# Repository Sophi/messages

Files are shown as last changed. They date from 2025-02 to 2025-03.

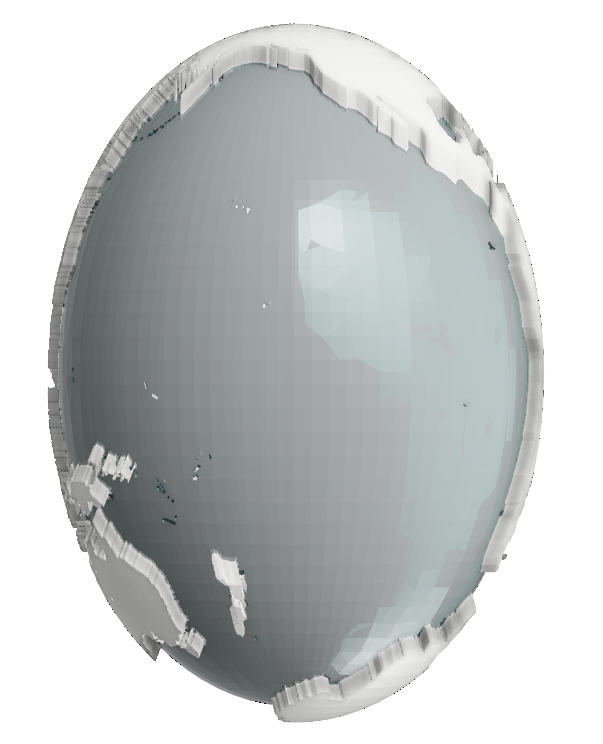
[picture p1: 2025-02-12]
extras/globe v2 screenshots/Screenshot 2024-12-30 113259.png

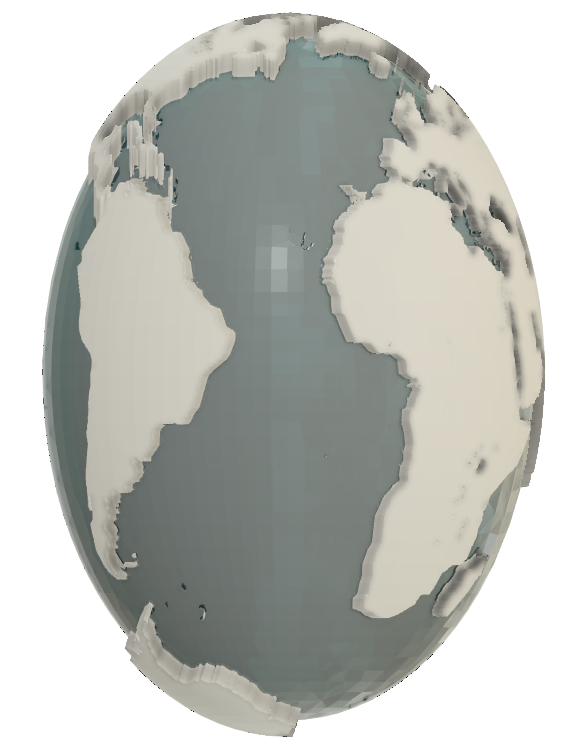
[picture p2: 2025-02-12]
extras/globe v2 screenshots/Screenshot 2024-12-30 112406.png

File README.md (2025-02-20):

# messages
WIP!

Imagine a field of glowing, planet-like orbs floating above you, each one pulsing with an unseen cosmic rhythm. These cosmic eggs capture real cosmic rays —high-energy particles from space— and translates them into an evolving, generated soundscape. The result is an unpredictable, meditative audio experience, where Space itself becomes an invisible composer. Lying beneath them, you hear the universe whisper in tones that are ethereal, textured, and deeply immersive. It’s a piece about connection, inviting us to rethink Earth’s place in the cosmos.

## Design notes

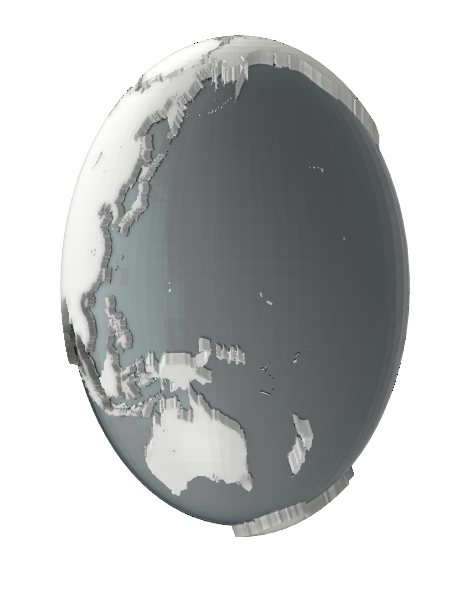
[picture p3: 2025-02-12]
extras/globe v2 screenshots/Screenshot 2024-12-30 111828.png

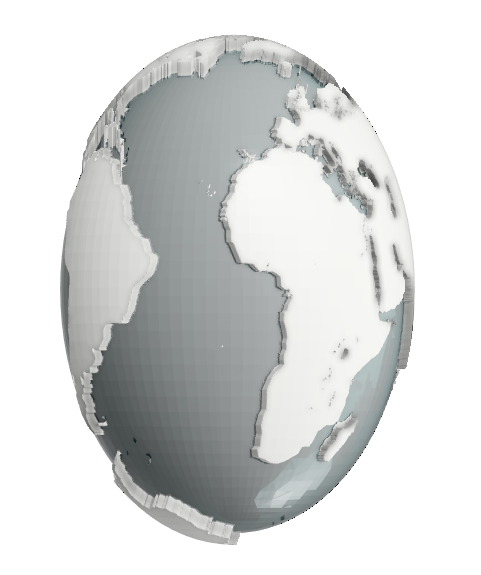
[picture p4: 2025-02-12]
extras/globe v2 screenshots/Screenshot 2024-12-30 104859.png

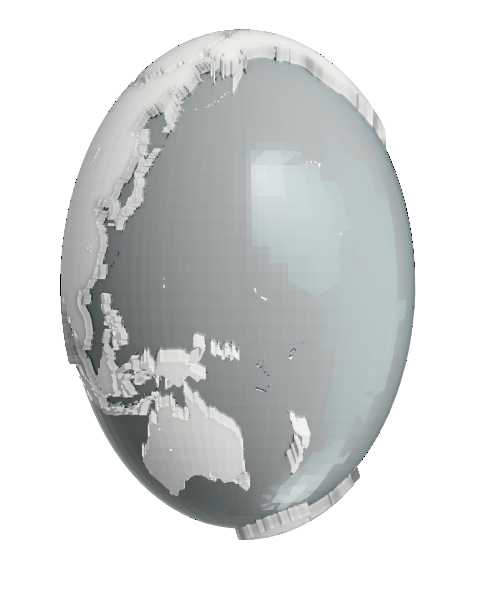
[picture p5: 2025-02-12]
extras/globe v2 screenshots/Screenshot 2024-12-30 104828.png

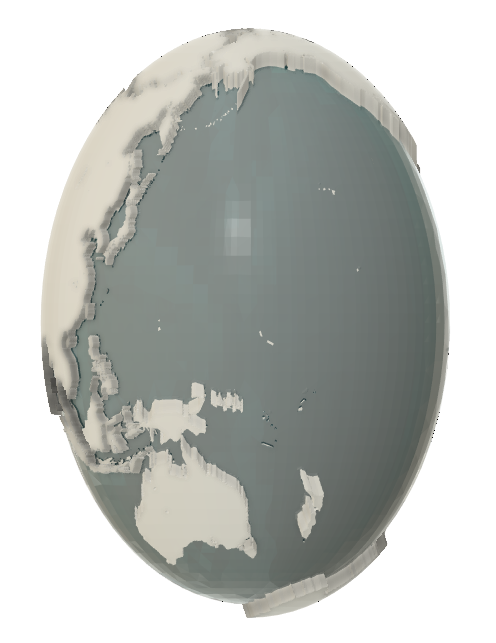
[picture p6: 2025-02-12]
extras/globe v2 screenshots/Screenshot 2024-12-30 111813.png

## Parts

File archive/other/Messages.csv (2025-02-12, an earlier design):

Reference | Value | Footprint | Qty | MPN | ALT MPN
C1 | 1uF/ 500V | Capacitor_SMD:C_2220_5750Metric | 1 | CHV2220N500105KXT
C2,C3,C17,C19,C20,C21,C22,C23,C24 | 0.1uF | Capacitor_SMD:C_0805_2012Metric | 9 | CC0805KRX7R9BB104
C4 | 120pF | Capacitor_SMD:C_0805_2012Metric | 1 | C0805C121J5GACTU
C5,C6,C10 | 1uF | Capacitor_SMD:C_0805_2012Metric | 3 | CC0805KKX5R6BB105
C7,C8,C9,C16,C18 | 10uF | Capacitor_SMD:C_0805_2012Metric | 5 | CL21B106KPQNNNE
C11,C12,C25 | 0.01uF | Capacitor_SMD:C_0805_2012Metric | 3 | C0805C103K5RACTU
C13,C26 | 2.2uF | Capacitor_SMD:C_0805_2012Metric | 2 | LMK212BJ225KD-T
C14,C15 | 2.2nF | Capacitor_SMD:C_0805_2012Metric | 2 | LMK212BJ225KD-T
D1 | ES1H | ES1H:DIOM4226X244N | 1 | ES1H
D2,D14 | YELLOW | LED_SMD:LED_0805_2012Metric | 2 | 150080YS75000
D3 | D_Schottky | Diode_SMD:D_SOD-323 | 1 | 1SS367,H3F
D4,D8 | GREEN | LED_SMD:LED_0805_2012Metric | 2 | 150080GS75000
D5,D6,D7,D10,D11,D12 | ESD9B5.0ST5G | Diode_SMD:D_SOD-923 | 6 | ESD9B5.0ST5G
D9,D13 | BLUE | LED_SMD:LED_0805_2012Metric | 2 | -- mixed values --
F1 | Clip | Fuse:Fuseholder_Clip-7.62mm_Littelfuse | 1 | 01220088Z
J1,J2 | USB4105-GF-A | USB4105-GF-A:GCT_USB4105-GF-A | 2 | USB4105-GF-A
J3 | AUDIO JACK | STX_3000:STX-3000_KYC | 1 | STX-3000
J4 | MEM2061-01-188-00-A | MEM2061 SD CARD CONNECTOR:MEM2061-01-188-00-A_GCT | 1 | MEM2061-01-188-00-A
J5 | 1x6 header | Connector_PinHeader_2.54mm:PinHeader_1x06_P2.54mm_Vertical | 1 | 61300611121
L1 | 2.2uH | Inductor_SMD:L_1008_2520Metric | 1 | DFE252012F-2R2M=P2
LS1 | CMI-1295IC-0385T | CMI_1295IC_0385T:CUI_CMI-1295IC-0385T | 1 | CMI-1295IC-0385T
Q1 | AO3400A | Package_TO_SOT_SMD:SOT-23 | 1 | AO3400A
Q2,Q3 | 2N7002-TP | Package_TO_SOT_THT:TO-92_Inline | 2 | 2N7002-TP
Q4 | BC846 | Package_TO_SOT_SMD:SOT-23 | 1 | BC846B_R1_00001
R1,R2 | 220R | Resistor_SMD:R_0805_2012Metric | 2 | RK73B2ATTD221J
R3 | 560k, 1M | Resistor_SMD:R_2512_6332Metric | 1 | CRGP2512F560K | CRGP2512F1M0
R4 | 715R | Resistor_SMD:R_0805_2012Metric | 1 | CRCW0805715RFKEA
R5 | 1K | Resistor_SMD:R_0805_2012Metric | 1 | RNCP0805FTD1K00
R6,R8,R23,R24,R28 | 4.7k | Resistor_SMD:R_0805_2012Metric | 5 | CRCW08054K70FKEAC
R7 | 5R | Resistor_SMD:R_0805_2012Metric | 1 | RC0805FR-0710RL | RMCF0603FT10R0
R9 | 2.7k | Resistor_SMD:R_0805_2012Metric | 1 | CRG0805F2K7
R10,R11,R13,R16,R20,R22,R32,R33,R34 | 10k | Resistor_SMD:R_0805_2012Metric | 9 | RMCF0805FT10K0
R12,R14,R18,R21 | 5.1k | Resistor_SMD:R_0805_2012Metric | 4 | RC0805JR-075K1L
R15,R31 | 1M | Resistor_SMD:R_0805_2012Metric | 2 | RC0805JR-071ML
R17,R19 | 22R | Resistor_SMD:R_0805_2012Metric | 2 | RC0805FR-0722RL
R25,R26,R27 | 33R | Resistor_SMD:R_0805_2012Metric | 3 | RC0805FR-0733RL
R29,R30 | 470R | Resistor_SMD:R_0805_2012Metric | 2 | CRGCQ0805J470R
S1,S2,S3 | SKRPABE010 | SKRPABE010:SW_SKRPABE010 | 3 | SKRPABE010
S4 | DS04-254-2-06BK-SMT | DIP switch:DIP SWITCH SW_DS04-254-2-06BK-SMT | 1 | DS04-254-2-06BK-SMT
T1 | FL2810-1L | Transformer_SMD:Transformer_Coilcraft_FL2810-1L | 1 | FL2810-1L
U1 | TPS2115APWR | TPS2115APWR:PW8 | 1 | TPS2115APWR
U2 | RP115X | Package_TO_SOT_SMD:SOT-89-5 | 1 | RP115H331D-T1-FE
U3 | TPS613222ADBV | Package_TO_SOT_SMD:SOT-23-5 | 1 | TPS613222ADBV
U4 | ESP32-S3-WROOM-1-N8 | KiCad:ESP32S3WROOM1N8R2 | 1 | ESP32-S3-WROOM-1-N8
U5 | FT231XS | Package_SO:SSOP-20_3.9x8.7mm_P0.635mm | 1 | FT231XS-R
U6 | PCM5102 | Package_SO:TSSOP-20_4.4x6.5mm_P0.65mm | 1 | PCM5102APWR

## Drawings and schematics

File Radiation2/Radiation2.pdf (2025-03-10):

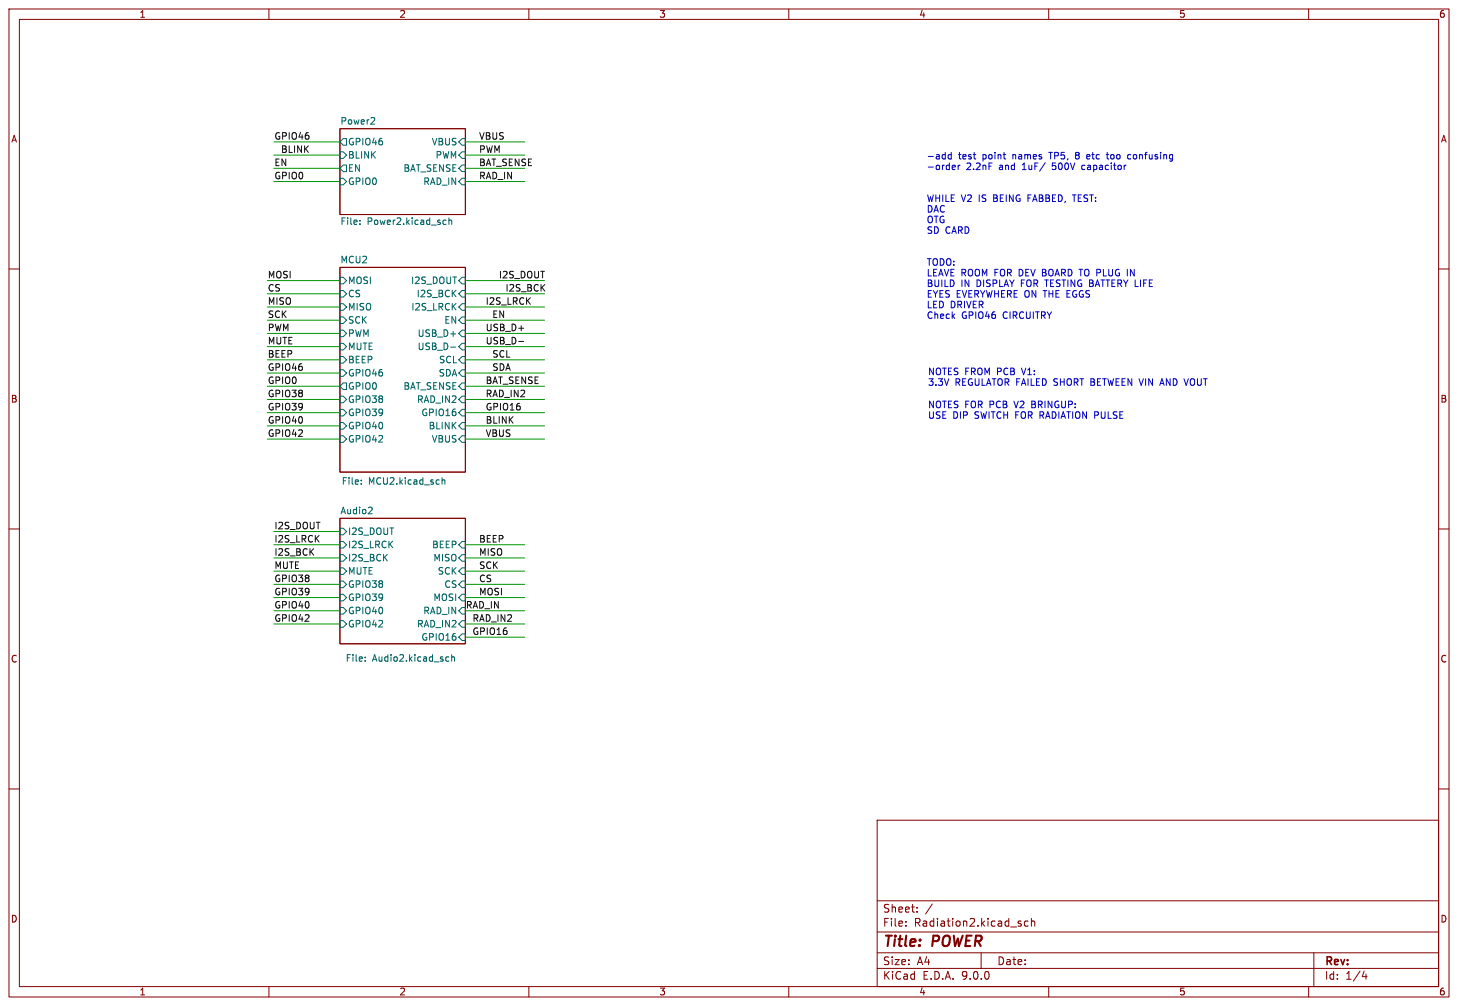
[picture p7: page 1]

TODO: LEAVE ROOM FOR DEV BOARD TO PLUG IN

BUILD IN DISPLAY FOR TESTING BATTERY LIFE
EYES EVERYWHERE ON THE EGGS
LED DRIVER
Check GPIO46 CIRCUITRY

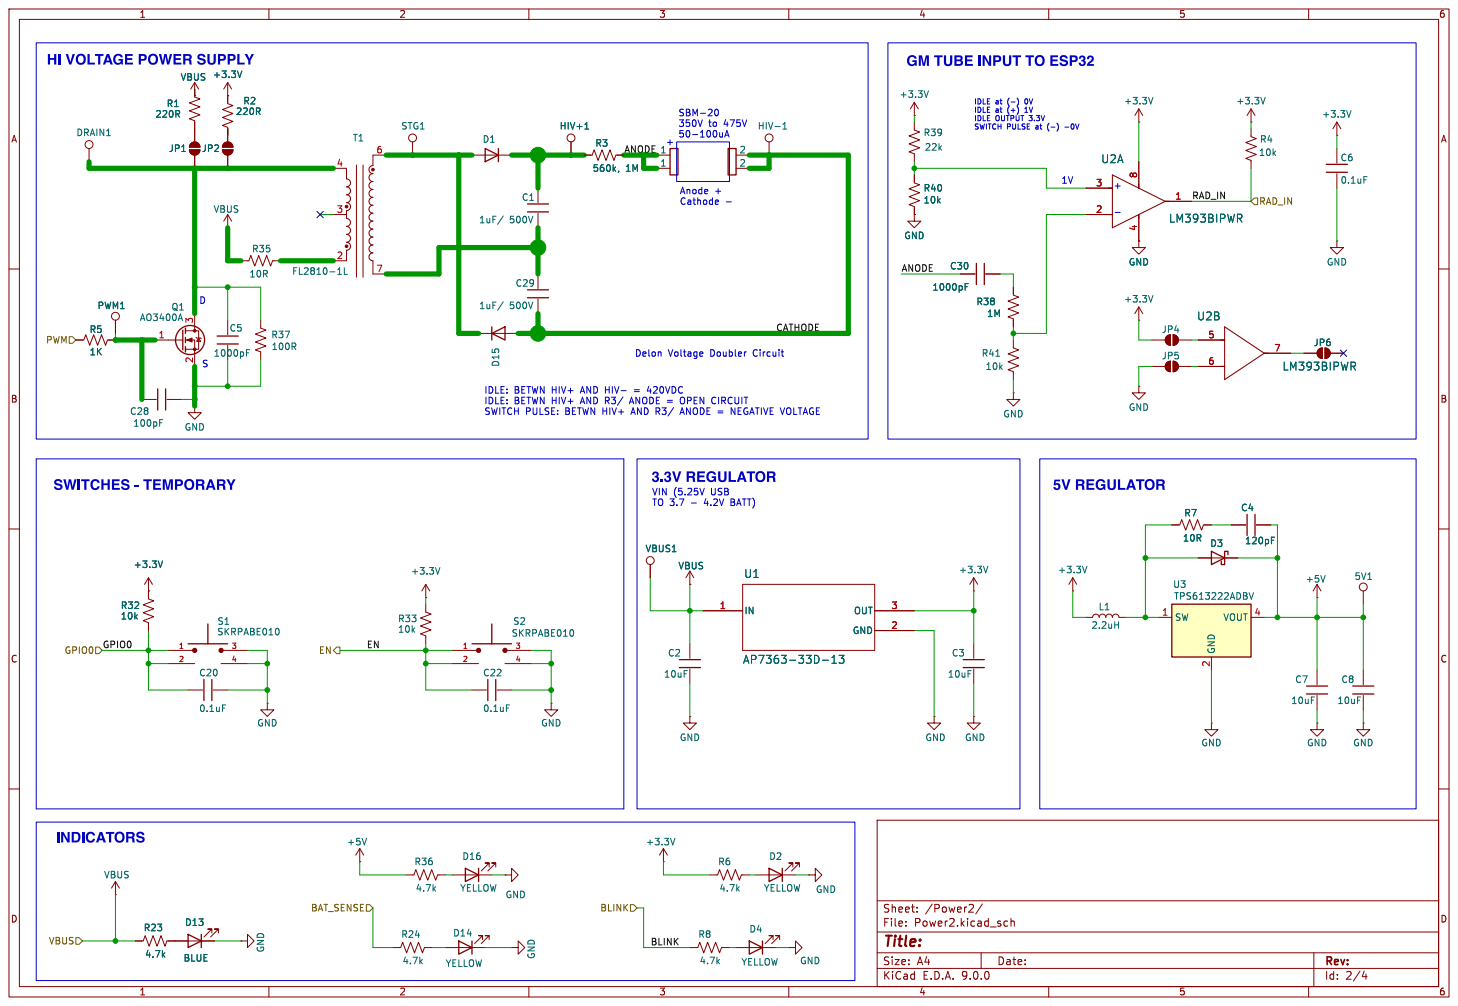
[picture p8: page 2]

Anode + Cathode - VIN (5.25V USB

PWM
TO 3.7 - 4.2V BATT) S SWITCHES - TEMPORARY

IDLE: BETWN HIV+ AND HIV- = 420VDC
IDLE: BETWN HIV+ AND R3/ ANODE = OPEN CIRCUIT SWITCH PULSE: BETWN HIV+ AND R3/ ANODE = NEGATIVE VOLTAGE

Id: 2/4 Title: File: Power2.kicad_sch Sheet: /Power2/

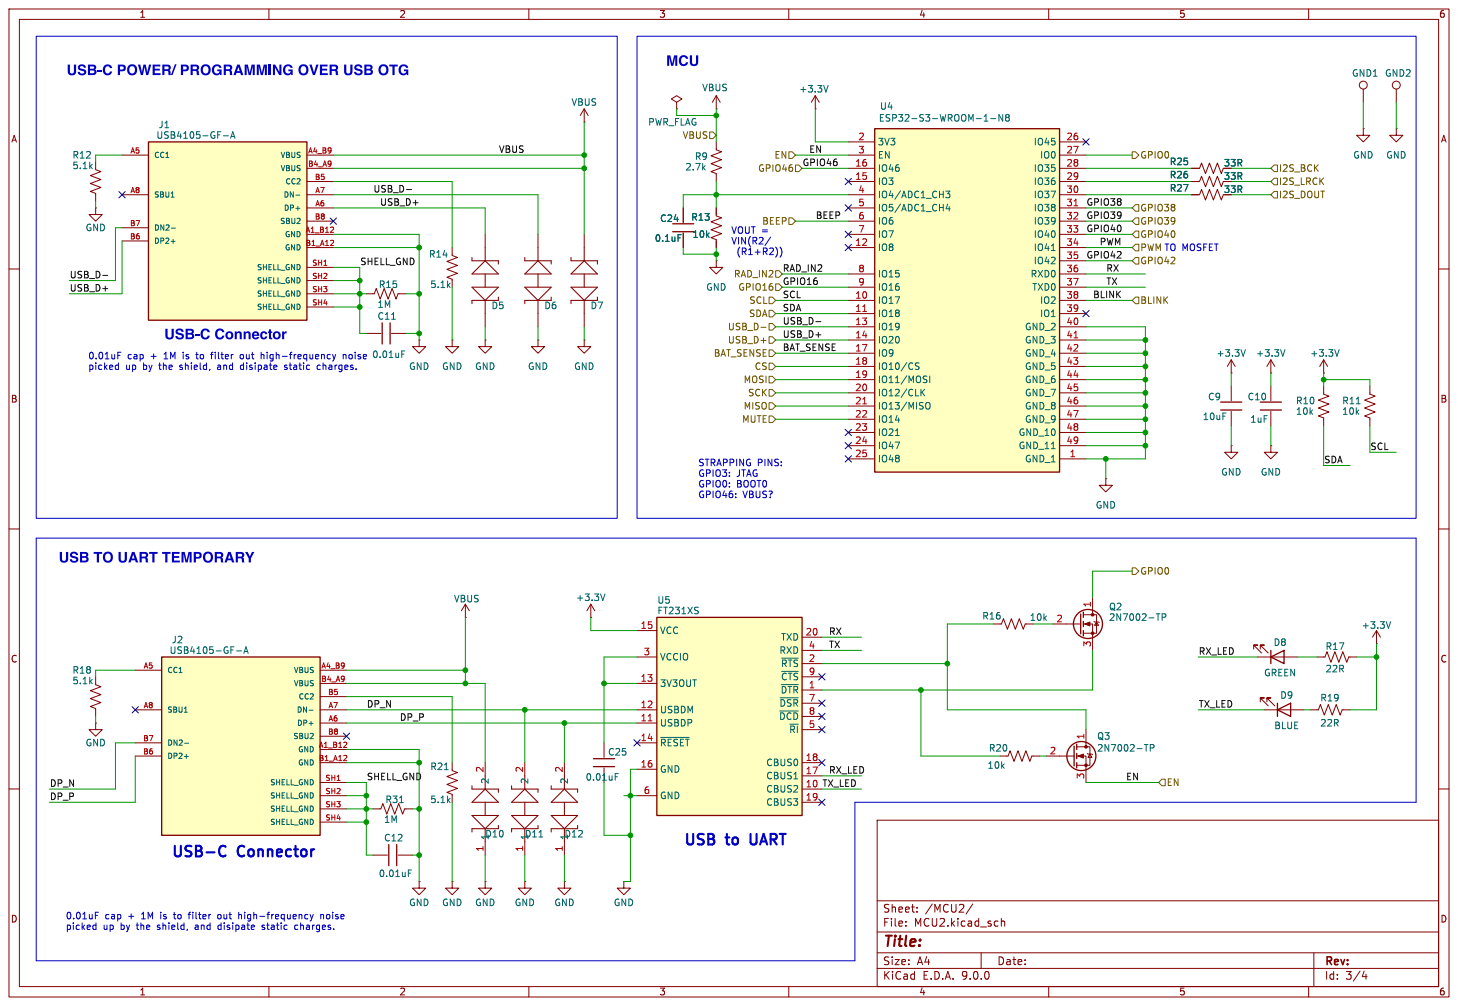
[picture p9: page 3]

USB-C POWER/ PROGRAMMING OVER USB OTG

22R GND
TO MOSFET USB TO UART TEMPORARY

Id: 3/4 Title: File: MCU2.kicad_sch Sheet: /MCU2/

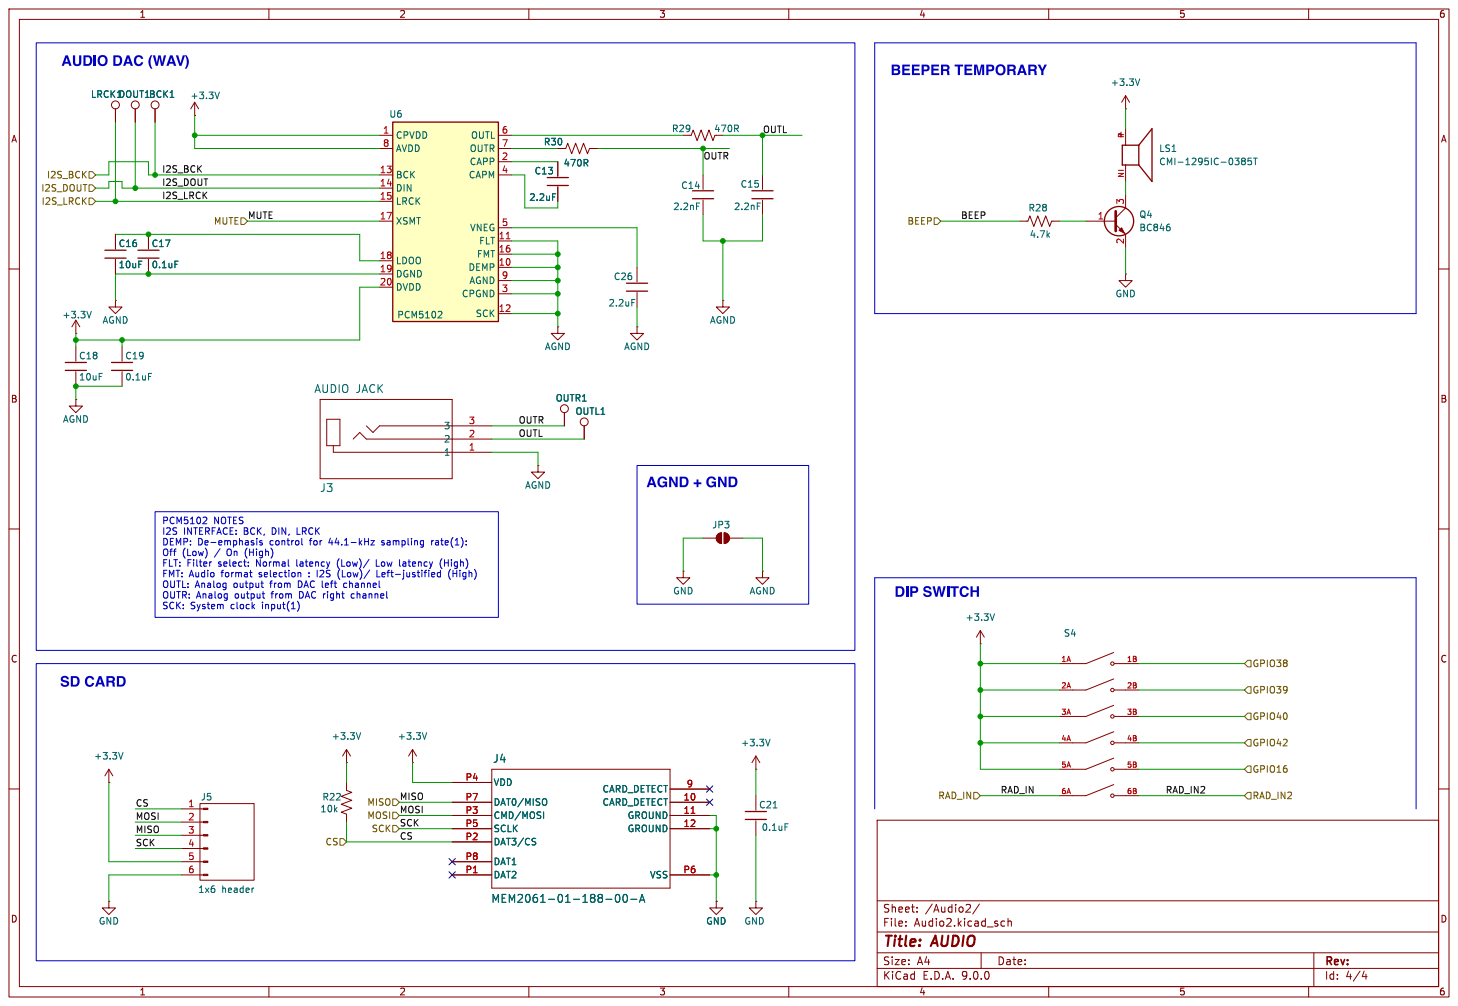
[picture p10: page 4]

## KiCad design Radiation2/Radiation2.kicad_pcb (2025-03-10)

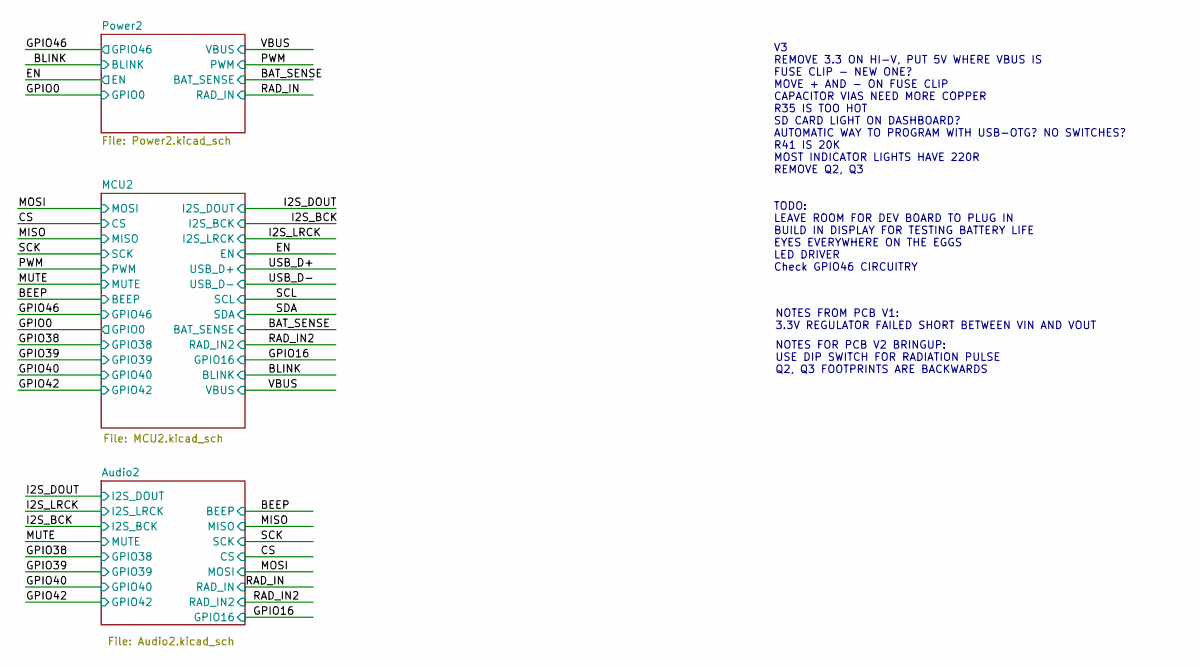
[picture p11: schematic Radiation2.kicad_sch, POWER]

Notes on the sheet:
V3 REMOVE 3.3 ON HI-V, PUT 5V WHERE VBUS IS FUSE CLIP - NEW ONE? MOVE + AND - ON FUSE CLIP CAPACITOR VIAS NEED MORE COPPER R35 IS TOO HOT SD CARD LIGHT ON DASHBOARD? AUTOMATIC WAY TO PROGRAM WITH USB-OTG? NO SWITCHES? R41 IS 20K MOST INDICATOR LIGHTS HAVE 220R REMOVE Q2, Q3 TODO: LEAVE ROOM FOR DEV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
NOTES FOR PCB V2 BRINGUP: USE DIP SWITCH FOR RADIATION PULSE Q2, Q3 FOOTPRINTS ARE BACKWARDS
NOTES FROM PCB V1: 3.3V REGULATOR FAILED SHORT BETWEEN VIN AND VOUT

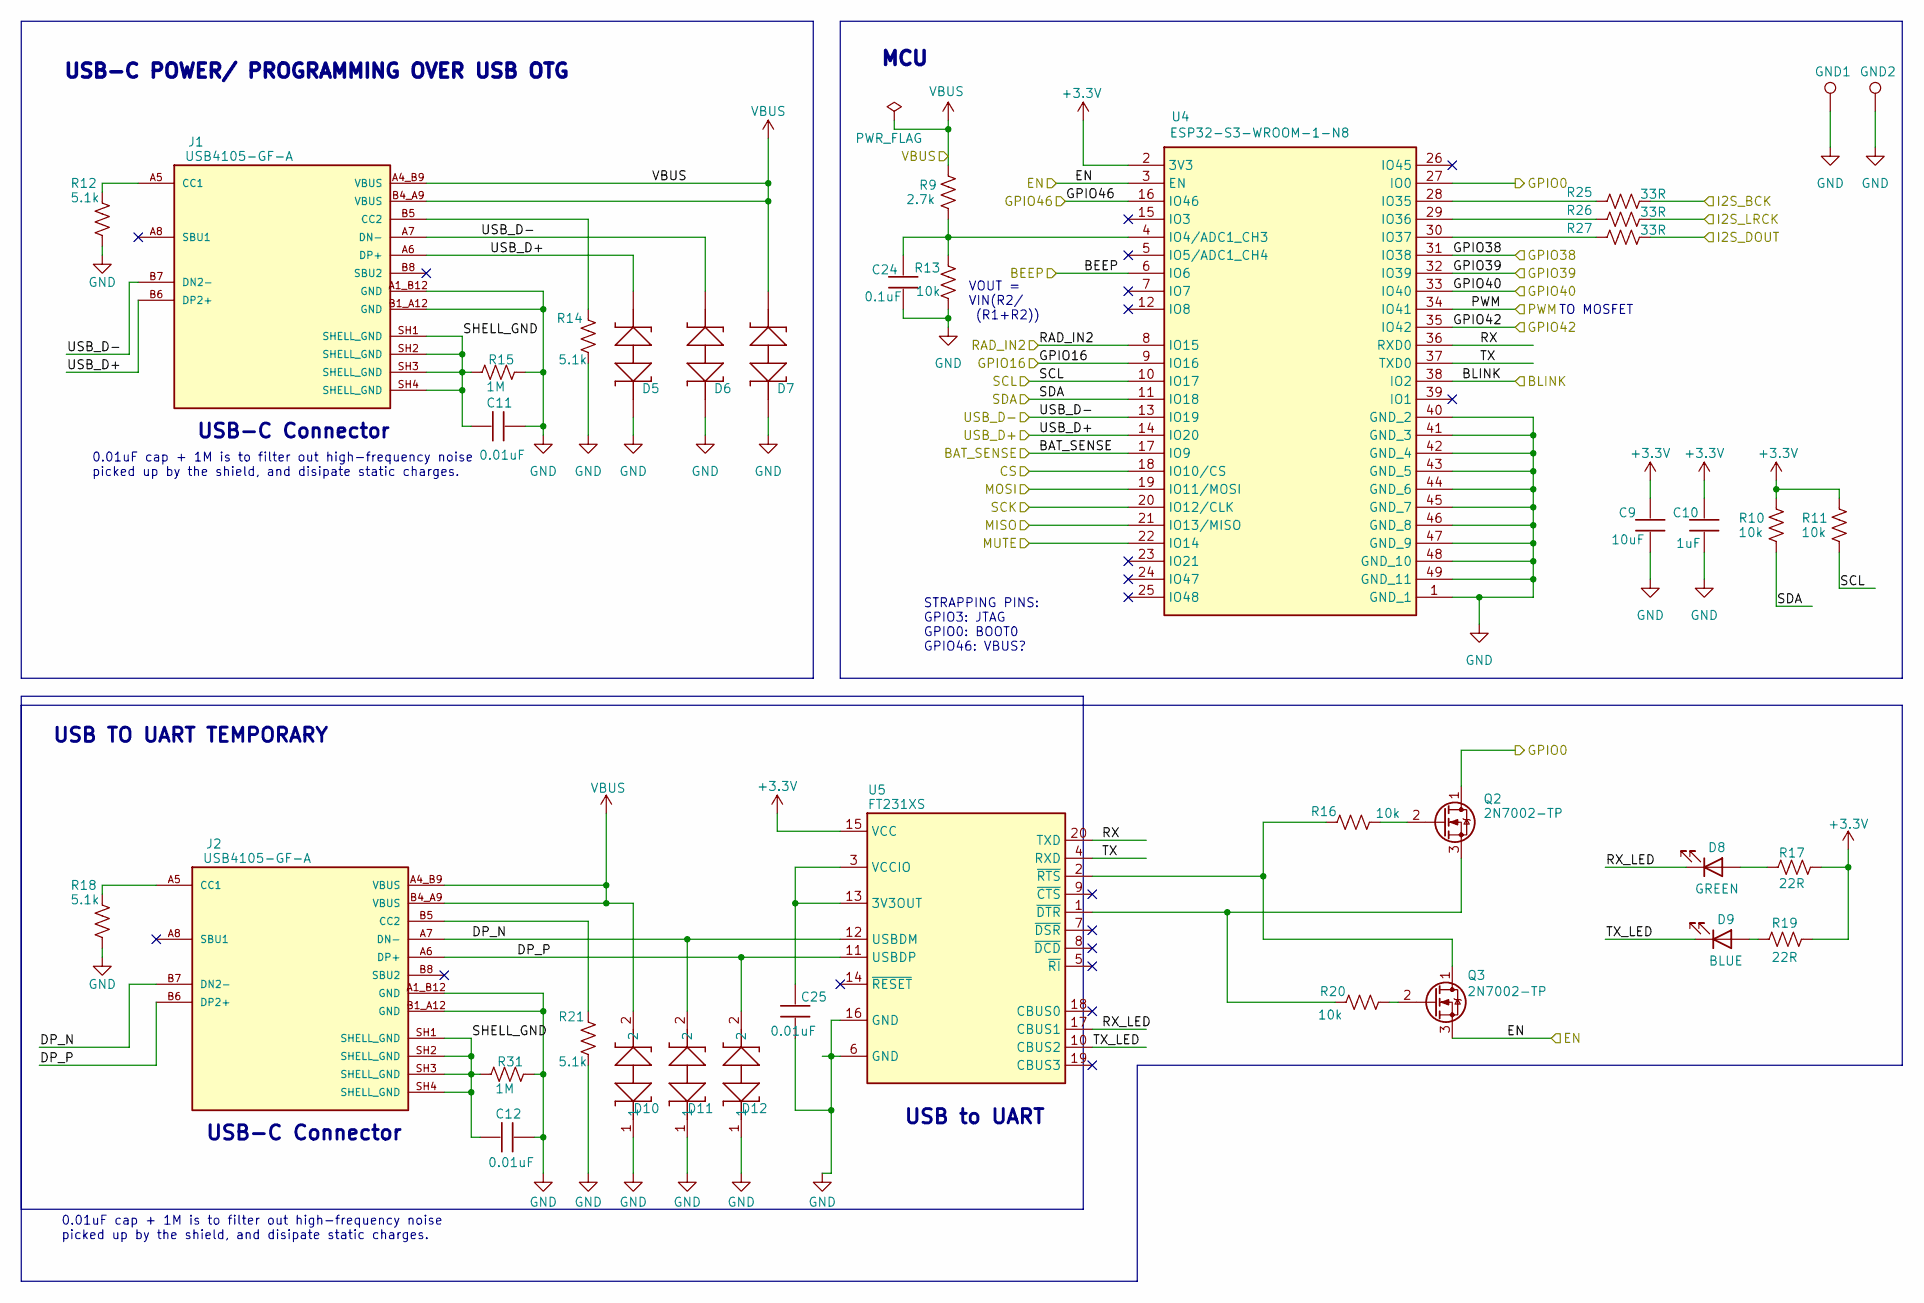
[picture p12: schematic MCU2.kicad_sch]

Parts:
C9: 10uF; C_0805_2012Metric; MPN CL21B106KPQNNNE
C10: 1uF; C_0805_2012Metric; MPN CC0805KKX5R6BB105
C11, C12, C25: 0.01uF; C_0805_2012Metric; MPN C0805C103K5RACTU
C24: 0.1uF; C_0805_2012Metric; MPN CC0805KRX7R9BB104
D5, D6, D7, D10, D11, D12: PESD5V0S1BA; SOD323_NXP; MPN PESD5V0S1BA,115
D8: GREEN; LED_0805_2012Metric; MPN 150080GS75000
D9: BLUE; LED_0805_2012Metric; MPN 150080BS75000
GND1, GND2: TestPoint; Pin_D1.0mm_L10.0mm
J1, J2: USB4105-GF-A; GCT_USB4105-GF-A; MPN USB4105-GF-A
Q2, Q3: 2N7002-TP; SOT-23; MPN 2N7002-TP
R9: 2.7k; R_0805_2012Metric; MPN CRG0805F2K7
R10, R11, R13, R16, R20: 10k; R_0805_2012Metric; MPN RMCF0805FT10K0
R12, R14, R18, R21: 5.1k; R_0805_2012Metric; MPN RC0805JR-075K1L
R15, R31: 1M; R_0805_2012Metric; MPN RC0805JR-071ML
R17, R19: 22R; R_0805_2012Metric; MPN RC0805FR-0722RL
R25, R26, R27: 33R; R_0805_2012Metric; MPN RC0805FR-0733RL
U4: ESP32-S3-WROOM-1-N8; ESP32S3WROOM1N8R2; Mouser Part Number 356-ESP32-S3WROOM1N8
U5: FT231XS; SSOP-20_3.9x8.7mm_P0.635mm; MPN FT231XS-R

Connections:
+3.3V: C9.1, C10.1, R10.2, R11.2, R17.1, R19.1, U4.2 (3V3), U5.15 (VCC); also elsewhere on the board
/BAT_SENSE: U4.17 (IO9); also elsewhere on the board
/BEEP: U4.6 (IO6); also elsewhere on the board
/BLINK: U4.38 (IO2); also elsewhere on the board
/CS: U4.18 (IO10/CS); also elsewhere on the board
/EN: Q3.3 (S), U4.3 (EN); also elsewhere on the board
/GPIO0: Q2.1 (D), U4.27 (IO0); also elsewhere on the board
/GPIO16: U4.9 (IO16); also elsewhere on the board
/GPIO38: U4.31 (IO38); also elsewhere on the board
/GPIO39: U4.32 (IO39); also elsewhere on the board
/GPIO40: U4.33 (IO40); also elsewhere on the board
/GPIO42: U4.35 (IO42); also elsewhere on the board
/GPIO46: U4.16 (IO46); also elsewhere on the board
/I2S_BCK: R25.1; also elsewhere on the board
/I2S_DOUT: R27.1; also elsewhere on the board
/I2S_LRCK: R26.1; also elsewhere on the board
/MCU2/DP_N: D11.2, J2.A7 (DN-), J2.B7 (DN2-), U5.12 (USBDM)
/MCU2/DP_P: D12.2, J2.A6 (DP+), J2.B6 (DP2+), U5.11 (USBDP)
/MCU2/RX: U4.36 (RXD0), U5.20 (TXD)
/MCU2/RX_LED: D8.1 (K), U5.17 (CBUS1)
/MCU2/SHELL_GND: C11.2, C12.2, J1.SH1 (SHELL_GND), J1.SH2 (SHELL_GND), J1.SH3 (SHELL_GND), J1.SH4 (SHELL_GND), J2.SH1 (SHELL_GND), J2.SH2 (SHELL_GND), J2.SH3 (SHELL_GND), J2.SH4 (SHELL_GND), R15.1, R31.1
/MCU2/TX: U4.37 (TXD0), U5.4 (RXD)
/MCU2/TX_LED: D9.1 (K), U5.10 (CBUS2)
/MISO: U4.21 (IO13/MISO); also elsewhere on the board
/MOSI: U4.19 (IO11/MOSI); also elsewhere on the board
/MUTE: U4.22 (IO14); also elsewhere on the board
/PWM: U4.34 (IO41); also elsewhere on the board
/RAD_IN2: U4.8 (IO15); also elsewhere on the board
/SCK: U4.20 (IO12/CLK); also elsewhere on the board
/SCL: R11.1, U4.10 (IO17)
/SDA: R10.1, U4.11 (IO18)
/USB_D+: D5.2, J1.A6 (DP+), J1.B6 (DP2+), U4.14 (IO20)
/USB_D-: D6.2, J1.A7 (DN-), J1.B7 (DN2-), U4.13 (IO19)
GND: C9.2, C10.2, C11.1, C12.1, C24.2, C25.1, D5.1, D6.1, D7.1, D10.1, D11.1, D12.1, GND1.1, GND2.1, J1.A1_B12 (GND), J1.B1_A12 (GND), J2.A1_B12 (GND), J2.B1_A12 (GND), R12.2, R13.1, R14.2, R15.2, R18.2, R21.2, R31.2, U4.1 (GND_1), U4.40 (GND_2), U4.41 (GND_3), U4.42 (GND_4), U4.43 (GND_5), U4.44 (GND_6), U4.45 (GND_7), U4.46 (GND_8), U4.47 (GND_9), U4.48 (GND_10), U4.49 (GND_11), U5.6 (GND), U5.16 (GND); also elsewhere on the board
unnamed: D8.2 (A), R17.2
unnamed: D9.2 (A), R19.2
unnamed: J1.A5 (CC1), R12.1
unnamed: J1.B5 (CC2), R14.1
unnamed: J2.A5 (CC1), R18.1
unnamed: J2.B5 (CC2), R21.1
unnamed: Q2.2 (G), R16.1
unnamed: Q2.3 (S), R20.2, U5.1 (~DTR)
unnamed: Q3.1 (D), R16.2, U5.2 (~RTS)
unnamed: Q3.2 (G), R20.1
unnamed: C24.1, R9.1, R13.2, U4.4 (IO4/ADC1_CH3)
unnamed: R25.2, U4.28 (IO35)
unnamed: R26.2, U4.29 (IO36)
unnamed: R27.2, U4.30 (IO37)
unnamed: C25.2, U5.3 (VCCIO), U5.13 (3V3OUT)
VBUS: D7.2, D10.2, J1.A4_B9 (VBUS), J1.B4_A9 (VBUS), J2.A4_B9 (VBUS), J2.B4_A9 (VBUS), R9.2; also elsewhere on the board

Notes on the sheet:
USB-C POWER/ PROGRAMMING OVER USB OTG
0.01uF cap + 1M is to filter out high-frequency noise picked up by the shield, and disipate static charges.
MCU
VOUT = VIN(R2/ (R1+R2))
USB TO UART TEMPORARY
TO MOSFET
USB-C Connector
STRAPPING PINS: GPIO3: JTAG GPIO0: BOOT0 GPIO46: VBUS?
USB to UART

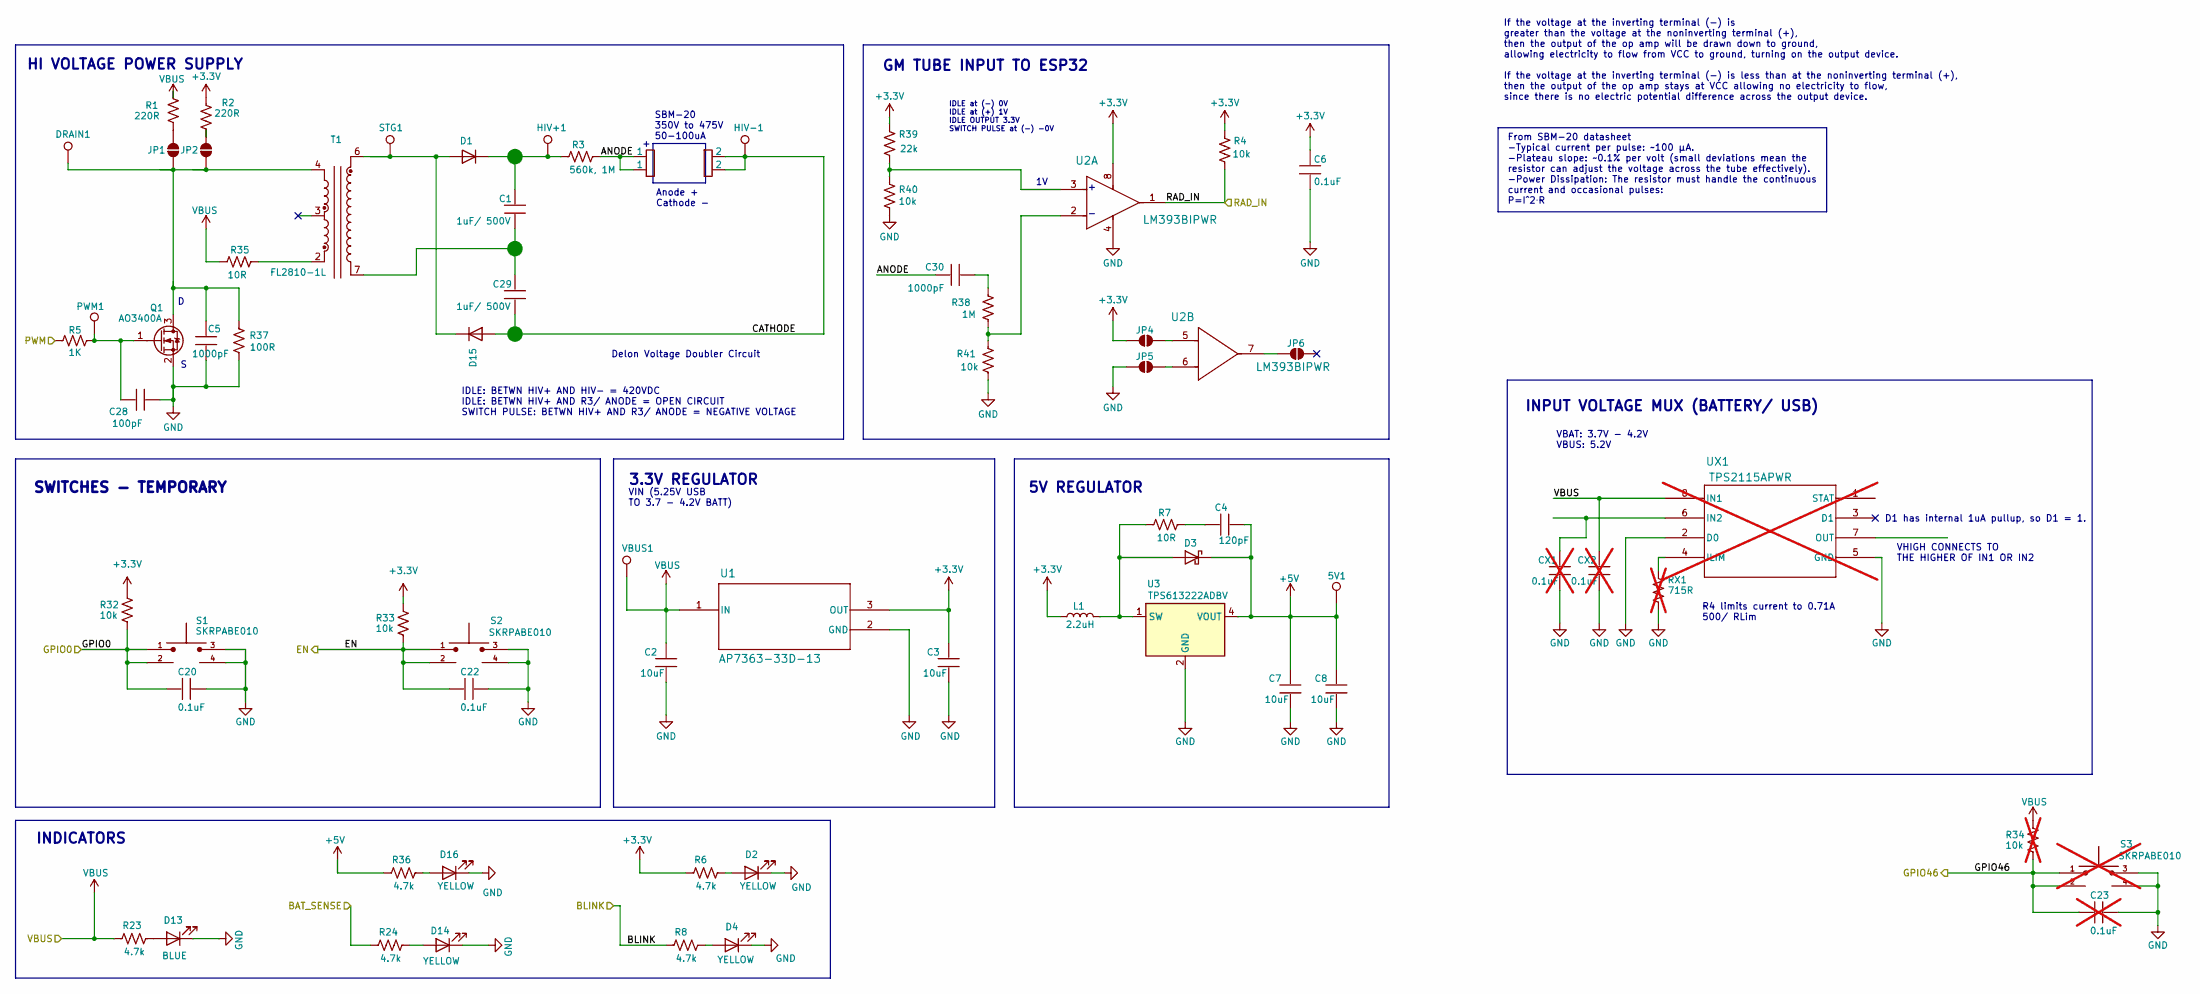
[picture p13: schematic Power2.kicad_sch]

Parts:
5V1: TestPoint; Pin_D1.0mm_L10.0mm
C1, C29: 1uF/ 500V; C_2220_5750Metric; MPN ECW-FD2J105K
C2, C3, C7, C8: 10uF; C_0805_2012Metric; MPN CL21B106KPQNNNE
C4: 120pF; C_0805_2012Metric; MPN C0805C121J5GACTU
C5, C30: 1000pF; C_0805_2012Metric; MPN C2012C0G2W102J060AA
C6, C20, C22: 0.1uF; C_0805_2012Metric; MPN CC0805KRX7R9BB104
C23: 0.1uF; C_0805_2012Metric; MPN CC0805KRX7R9BB104; not fitted
C28: 100pF; C_0805_2012Metric; MPN C0805C101J5GACTU
CX1, CX2: 0.1uF; C_0805_2012Metric; MPN CC0805KRX7R9BB104; not fitted
D1, D15: ES1H; DIOM4226X244N; MPN ES1H
D2, D4, D14, D16: YELLOW; LED_0805_2012Metric; MPN 150080YS75000
D3: D_Schottky; D_SOD-323; MPN 1SS367,H3F
D13: BLUE; LED_0805_2012Metric; MPN 150080BS75000
DRAIN1: TestPoint; Pin_D1.0mm_L10.0mm
F1: Clip; Fuseholder_Clip-7.62mm_Littelfuse; MPN 01220088Z
HIV+1: TestPoint; Pin_D1.0mm_L10.0mm
HIV-1: TestPoint; Pin_D1.0mm_L10.0mm
JP1, JP2, JP4, JP5, JP6: SolderJumper_2_Open; SolderJumper-2_P1.3mm_Open_RoundedPad1.0x1.5mm
L1: 2.2uH; L_1008_2520Metric; MPN DFE252012F-2R2M=P2
PWM1: TestPoint; Pin_D1.0mm_L10.0mm
Q1: AO3400A; SOT-23; MPN AO3400A
R1, R2: 220R; R_0805_2012Metric; MPN RK73B2ATTD221J
R3: 560k, 1M; R_2512_6332Metric; MPN CRGP2512F560K
R4: 10k; R_0805_2012Metric; MPN CRCW08054K70FKEAC
R5: 1K; R_0805_2012Metric; MPN RNCP0805FTD1K00
R6, R8, R23, R24, R36: 4.7k; R_0805_2012Metric; MPN CRCW08054K70FKEAC
R7: 10R; R_0805_2012Metric; MPN RMCF0603FT10R0
R32, R33, R40, R41: 10k; R_0805_2012Metric; MPN RMCF0805FT10K0
R34: 10k; R_0805_2012Metric; MPN RMCF0805FT10K0; not fitted
R35: 10R; R_2512_6332Metric; MPN 352210RJT
R37: 100R; R_0805_2012Metric; MPN ERJ-P06J101V
R38: 1M; R_1210_3225Metric; MPN RC1210FR-071ML
R39: 22k; R_0805_2012Metric; MPN RMCF0805JT22K0
RX1: 715R; R_0805_2012Metric; MPN CRCW0805715RFKEA; not fitted
S1, S2: SKRPABE010; SW_SKRPABE010; MPN SKRPABE010
S3: SKRPABE010; SW_SKRPABE010; MPN SKRPABE010; not fitted
STG1: TestPoint; Pin_D1.0mm_L10.0mm
T1: FL2810-1L; Transformer_Coilcraft_FL2810-1L; MPN FL2810-1L; Mouser Part Number 580-54100C
U1: AP7363-33D-13; TO252-3L_DIO
U2: LM393BIPWR; PW0008A-MFG
U3: TPS613222ADBV; SOT-23-5; MPN TPS613222ADBV
UX1: TPS2115APWR; PW8; MPN TPS2115APWR; not fitted
VBUS1: TestPoint; Pin_D1.0mm_L10.0mm

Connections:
+3.3V: C3.1, C6.2, JP4.2 (B), L1.1, R2.2, R4.2, R6.2, R32.2, R33.2, R39.2, U1.3 (OUT), U2.8 (VCC); also elsewhere on the board
+5V: 5V1.1, C4.1, C7.1, C8.1, D3.1 (K), R36.2, U3.4 (VOUT)
/BAT_SENSE: R24.2; also elsewhere on the board
/BLINK: R8.2; also elsewhere on the board
/EN: C22.2, R33.1, S2.1, S2.2; also elsewhere on the board
/GPIO0: C20.2, R32.1, S1.1, S1.2; also elsewhere on the board
/GPIO46: C23.2, R34.1, S3.1, S3.2; also elsewhere on the board
/PWM: R5.2; also elsewhere on the board
/Power2/ANODE: C30.1, F1.1, R3.1
/Power2/CATHODE: C29.1, D15.2 (A), F1.2, HIV-1.1
/RAD_IN: R4.1, U2.1 (1OUT); also elsewhere on the board
GND: C2.2, C3.2, C5.2, C6.1, C7.2, C8.2, C20.1, C22.1, C23.1, C28.2, CX1.2, CX2.2, D2.1 (K), D4.1 (K), D13.1 (K), D14.1 (K), D16.1 (K), JP5.2 (B), Q1.2 (S), R37.1, R40.1, R41.1, RX1.1, S1.3, S1.4, S2.3, S2.4, S3.3, S3.4, U1.2 (GND), U2.4 (GND), U3.2 (GND), UX1.2 (D0), UX1.5 (GND); also elsewhere on the board
unnamed: C1.1, C29.2, T1.7
unnamed: C4.2, R7.1
unnamed: C30.2, R38.2
unnamed: CX1.1, UX1.6 (IN2)
unnamed: CX2.1, UX1.8 (IN1)
unnamed: D1.2 (A), D15.1 (K), STG1.1, T1.6
unnamed: C1.2, D1.1 (K), HIV+1.1, R3.2
unnamed: D2.2 (A), R6.1
unnamed: D3.2 (A), L1.2, R7.2, U3.1 (SW)
unnamed: D4.2 (A), R8.1
unnamed: D13.2 (A), R23.1
unnamed: D14.2 (A), R24.1
unnamed: D16.2 (A), R36.1
unnamed: C5.1, DRAIN1.1, JP1.1 (A), JP2.1 (A), Q1.3 (D), R37.2, T1.4
unnamed: JP1.2 (B), R1.1
unnamed: JP2.2 (B), R2.1
unnamed: JP4.1 (A), U2.5 (2IN+)
unnamed: JP5.1 (A), U2.6 (2IN-)
unnamed: JP6.2 (B), U2.7 (2OUT)
unnamed: C28.1, PWM1.1, Q1.1 (G), R5.1
unnamed: R35.1, T1.2
unnamed: RX1.2, UX1.4 (ILIM)
unnamed: R39.1, R40.2, U2.3 (1IN+)
unnamed: R38.1, R41.2, U2.2 (1IN-)
VBUS: C2.1, R1.2, R23.2, R34.2, R35.2, U1.1 (IN), VBUS1.1; also elsewhere on the board

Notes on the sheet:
5V REGULATOR
D1 has internal 1uA pullup, so D1 = 1.
GM TUBE INPUT TO ESP32
INPUT VOLTAGE MUX (BATTERY/ USB)
INDICATORS
HI VOLTAGE POWER SUPPLY
If the voltage at the inverting terminal (-) is greater than the voltage at the noninverting terminal (+), then the output of the op amp will be drawn down to ground, allowing electricity to flow from VCC to ground, turning on the output device. If the voltage at the inverting terminal (-) is less 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
Delon Voltage Doubler Circuit
From SBM-20 datasheet -Typical current per pulse: ~100 µA. -Plateau slope: ~0.1% per volt (small deviations mean the resistor can adjust the voltage across the tube effectively). -Power Dissipation: The resistor must handle the continuous current and occasional pulses: P=I^2⋅R
R4 limits current to 0.71A 500/ RLim
VIN (5.25V USB TO 3.7 - 4.2V BATT)
3.3V REGULATOR
VHIGH CONNECTS TO THE HIGHER OF IN1 OR IN2
SWITCHES - TEMPORARY
Anode + Cathode -
VBAT: 3.7V - 4.2V VBUS: 5.2V
SBM-20 350V to 475V 50-100uA
IDLE at (-) 0V IDLE at (+) 1V IDLE OUTPUT 3.3V SWITCH PULSE at (-) -0V
IDLE: BETWN HIV+ AND HIV- = 420VDC IDLE: BETWN HIV+ AND R3/ ANODE = OPEN CIRCUIT SWITCH PULSE: BETWN HIV+ AND R3/ ANODE = NEGATIVE VOLTAGE

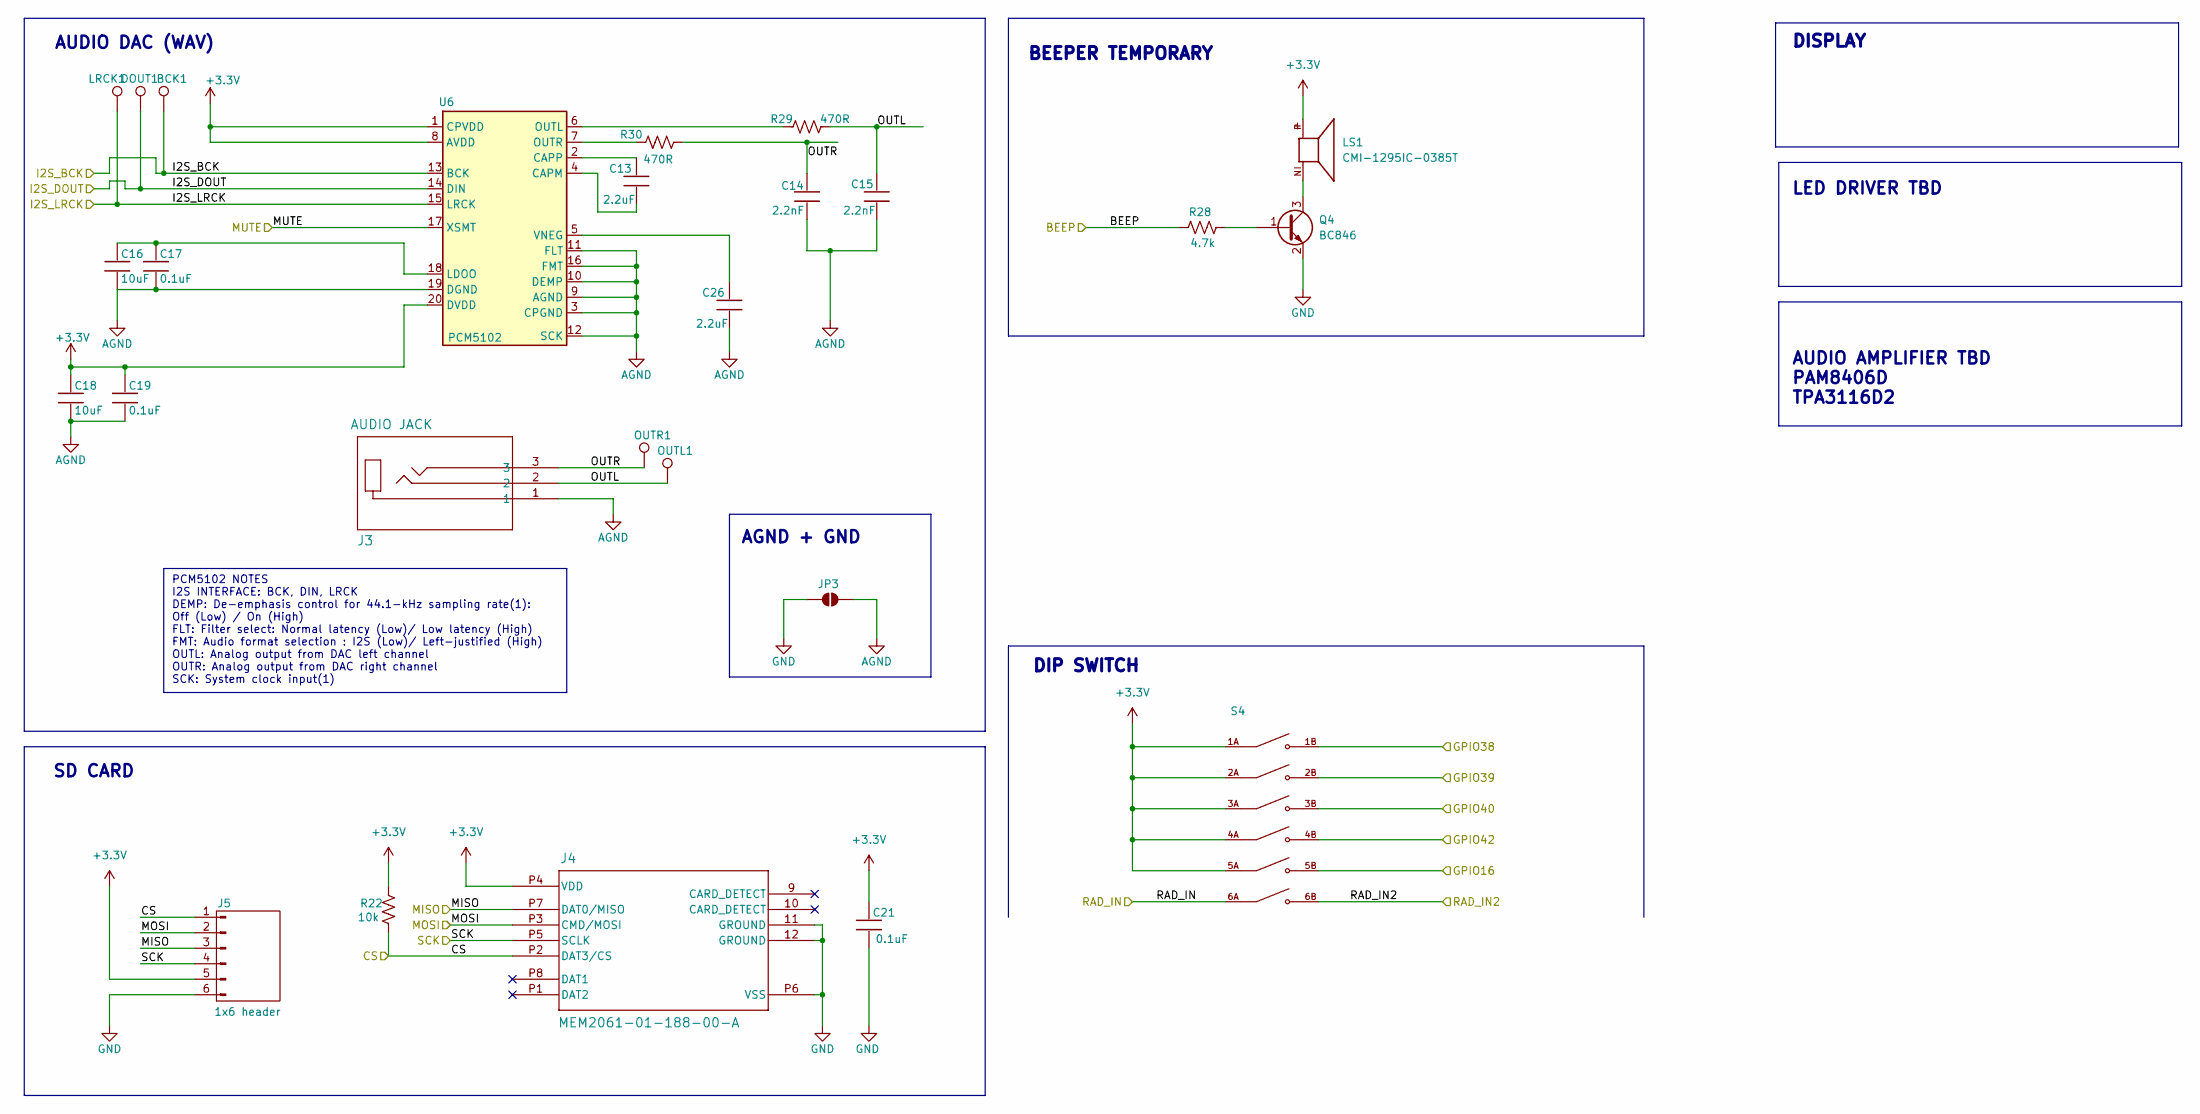
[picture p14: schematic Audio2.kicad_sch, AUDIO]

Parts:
BCK1: TestPoint; Pin_D1.0mm_L10.0mm
C13, C26: 2.2uF; C_0805_2012Metric; MPN LMK212BJ225KD-T
C14, C15: 2.2nF; C_0805_2012Metric; MPN C0805C222KCRACTU
C16, C18: 10uF; C_0805_2012Metric; MPN CL21B106KPQNNNE
C17, C19, C21: 0.1uF; C_0805_2012Metric; MPN CC0805KRX7R9BB104
DOUT1: TestPoint; Pin_D1.0mm_L10.0mm
J3: AUDIO JACK; STX-3000_KYC; MPN STX-3000
J4: MEM2061-01-188-00-A; MEM2061-01-188-00-A_GCT; MPN MEM2061-01-188-00-A
J5: 1x6 header; PinHeader_1x06_P2.54mm_Vertical; MPN 61300611121
JP3: SolderJumper_2_Open; SolderJumper-2_P1.3mm_Open_RoundedPad1.0x1.5mm
LRCK1: TestPoint; Pin_D1.0mm_L10.0mm
LS1: CMI-1295IC-0385T; CUI_CMI-1295IC-0385T; MPN CMI-1295IC-0385T
OUTL1: TestPoint; Pin_D1.0mm_L10.0mm
OUTR1: TestPoint; Pin_D1.0mm_L10.0mm
Q4: BC846; SOT-23; MPN BC846
R22: 10k; R_0805_2012Metric; MPN RMCF0805FT10K0
R28: 4.7k; R_0805_2012Metric; MPN CRCW08054K70FKEAC
R29, R30: 470R; R_0805_2012Metric; MPN CRGCQ0805J470R
S4: DS04-254-2-06BK-SMT; DIP SWITCH SW_DS04-254-2-06BK-SMT; MPN DS04-254-2-06BK-SMT
U6: PCM5102; TSSOP-20_4.4x6.5mm_P0.65mm; MPN PCM5102APWR

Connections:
+3.3V: C18.1, C19.1, C21.1, J4.P4 (VDD), J5.5, LS1.P, R22.1, S4.1A, S4.2A, S4.3A, S4.4A, S4.5A, U6.1 (CPVDD), U6.8 (AVDD), U6.20 (DVDD); also elsewhere on the board
/Audio2/OUTL: C15.1, J3.2, OUTL1.1, R29.1
/Audio2/OUTR: C14.1, J3.3, OUTR1.1, R30.1
/BEEP: R28.2; also elsewhere on the board
/CS: J4.P2 (DAT3/CS), J5.1, R22.2; also elsewhere on the board
/GPIO16: S4.5B; also elsewhere on the board
/GPIO38: S4.1B; also elsewhere on the board
/GPIO39: S4.2B; also elsewhere on the board
/GPIO40: S4.3B; also elsewhere on the board
/GPIO42: S4.4B; also elsewhere on the board
/I2S_BCK: BCK1.1, U6.13 (BCK); also elsewhere on the board
/I2S_DOUT: DOUT1.1, U6.14 (DIN); also elsewhere on the board
/I2S_LRCK: LRCK1.1, U6.15 (LRCK); also elsewhere on the board
/MISO: J4.P7 (DAT0/MISO), J5.3; also elsewhere on the board
/MOSI: J4.P3 (CMD/MOSI), J5.2; also elsewhere on the board
/MUTE: U6.17 (XSMT); also elsewhere on the board
/RAD_IN: S4.6A; also elsewhere on the board
/RAD_IN2: S4.6B; also elsewhere on the board
/SCK: J4.P5 (SCLK), J5.4; also elsewhere on the board
AGND: C14.2, C15.2, C16.2, C17.2, C18.2, C19.2, C26.2, J3.1, JP3.2 (B), U6.3 (CPGND), U6.9 (AGND), U6.10 (DEMP), U6.11 (FLT), U6.12 (SCK), U6.16 (FMT), U6.19 (DGND)
GND: C21.2, J4.11 (GROUND), J4.12 (GROUND), J4.P6 (VSS), J5.6, JP3.1 (A), Q4.2 (E); also elsewhere on the board
unnamed: Q4.1 (B), R28.1
unnamed: LS1.N, Q4.3 (C)
unnamed: C13.2, U6.4 (CAPM)
unnamed: C13.1, U6.2 (CAPP)
unnamed: C16.1, C17.1, U6.18 (LDOO)
unnamed: R29.2, U6.6 (OUTL)
unnamed: R30.2, U6.7 (OUTR)
unnamed: C26.1, U6.5 (VNEG)

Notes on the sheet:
LED DRIVER TBD
DIP SWITCH
DISPLAY
AUDIO DAC (WAV)
BEEPER TEMPORARY
PCM5102 NOTES I2S INTERFACE: BCK, DIN, LRCK DEMP: De-emphasis control for 44.1-kHz sampling rate(1): Off (Low) / On (High) FLT: Filter select: Normal latency (Low)/ Low latency (High) FMT: Audio format selection : I2S (Low)/ Left-justified (High) OUTL: Analog output from DAC left channel OUTR: Anal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
AGND + GND
AUDIO AMPLIFIER TBD PAM8406D TPA3116D2
SD CARD

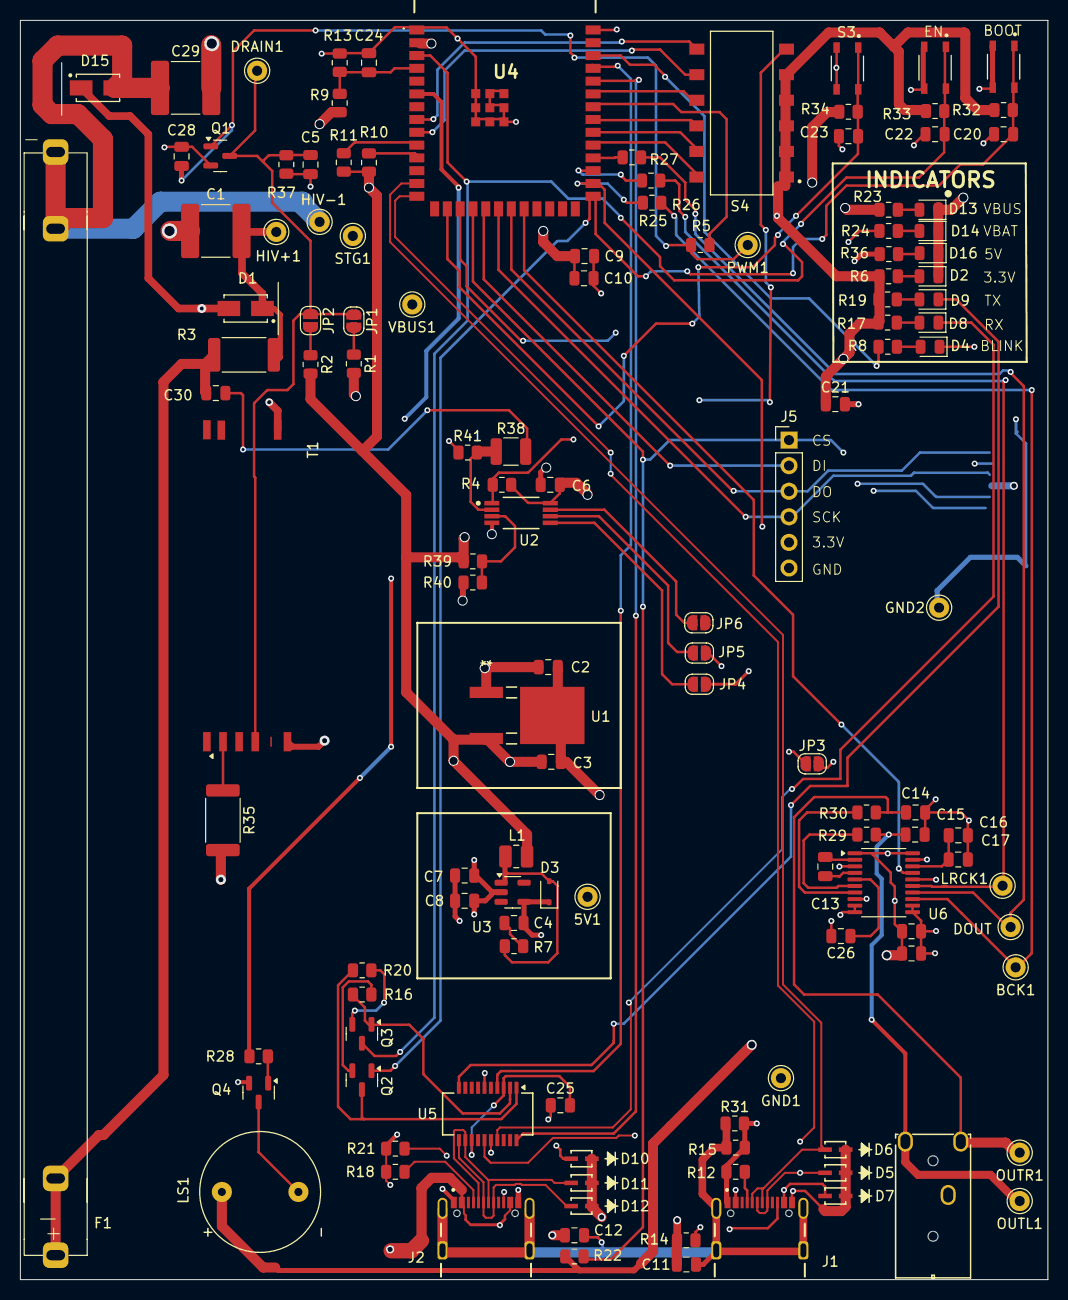
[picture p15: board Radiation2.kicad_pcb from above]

Board: 4 copper layers, 102.0 x 125.0 mm, 129 parts (1 on the bottom side), 86 nets.

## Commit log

2025-01-31 first schemtic/ PCB upload
    [Audio.kicad_sch, MCU.kicad_sch, Power.kicad_sch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]
2025-01-31 Updated schematics/ pcb
    [Audio.kicad_sch, MCU.kicad_sch, Radiation detector.kicad_sch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]
2025-01-31 revisions after design review by Ted Yapo
    [Audio.kicad_sch, MCU.kicad_sch, Radiation.kicad_pcb]
2025-02-01 proto 1 final
    [MCU.kicad_sch, Power.kicad_sch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]
2025-02-20 PCB v2
    [Audio2.kicad_sch, MCU2.kicad_sch, Power2.kicad_sch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]
2025-03-10 update V2
    [Audio.kicad_sch, Audio2.kicad_sch, MCU.kicad_sch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]
2025-04-11 Adding V3
    [Audio2.kicad_sch, MCU2.kicad_sch, Power2.kicad_sch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]
